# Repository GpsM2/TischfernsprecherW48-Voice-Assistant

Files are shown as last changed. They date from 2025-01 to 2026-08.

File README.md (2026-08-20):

# 📞 TischfernsprecherW48-Voice-Assistant 🗣️


Modification of a vintage "Tischfernsprecher W 48" telephone into a HomeAssistant-compatible voice assistant device

## 📝 Detailed Description
This project transforms the vintage "Tischfernsprecher W 48" telephone into a voice assistant. The device listens only when the handset is lifted, making it intuitive and eliminating the need for a wake word. Additionally, it combines the charm of a vintage telephone with modern functionality. ✨

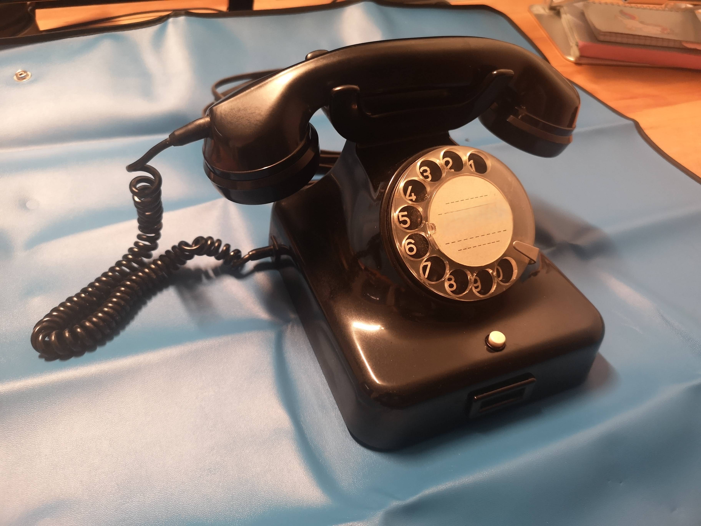
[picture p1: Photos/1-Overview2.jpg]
Phone


## 🛠️ Hardware Used
* [diymore ESP32 S3 DevKitC 1 N16R8 ESP32 S3 WROOM1 N16R8](https://www.amazon.de/gp/product/B0CLD4QKT1)
* [AZDelivery MAX98357A I2S 3W Mono Amplifier Class D](https://www.amazon.de/dp/B09PL7DSK5)
* [ARCELI 3PCS INMP441 Omnidirectional Microphone Module, I2S](https://www.amazon.de/dp/B0CH2TYXCZ)
* [Weewooday 6 Pieces 2W 8 Ohm Speaker](https://www.amazon.de/dp/B09MRK24PP)
* [chenyang RJ45 Stretch Spiral Cable Cat6 8P8C UTP](https://www.amazon.de/dp/B0CF2B2PCK) (at least 2 meters, 7 wires needed)

## 💻 Software Used
* [ESPHome](https://esphome.io/) **2026.4.0 or newer**, running as a Home Assistant add-on 🏠
* [YAML configuration file](tischfernsprecher-w48.yaml) 📄

### ⚙️ Setup
1. Copy [`secrets.yaml.example`](secrets.yaml.example) to `secrets.yaml` next to the configuration and fill in your Wi-Fi credentials and an API encryption key (generate one with `openssl rand -base64 32`). `secrets.yaml` is git-ignored and must stay out of the repository. If you are updating an existing device, reuse the key it already has — a new key means Home Assistant can no longer reach the device.
2. Adopt the configuration in the ESPHome dashboard and flash the device. It joins the configured network on its own; if that network is unreachable it opens its own access point and serves a captive portal, so it can be recovered without opening the housing.
3. In Home Assistant, assign an Assist pipeline to the device. Lifting the handset starts the pipeline — there is no wake word.

> **ESPHome version.** This configuration uses the current audio stack (`speaker` plus `media_player: speaker`). The older `media_player: i2s_audio` platform was **removed in ESPHome 2026.4.0**, so anything built from an earlier revision of this repository will no longer compile. The ESP-IDF framework is required and is already set in the configuration.

> **No PSRAM on this build.** The board is sold as an ESP32-S3 N16R8, which should mean 8 MB of octal PSRAM, but the one used here reports none: with `mode: octal` the second stage bootloader hangs before printing a single line, and with `mode: quad` the device boots and logs `PSRAM: Available: NO`. The configuration therefore ships without a `psram:` block, runs the whole audio chain at 16 kHz mono and keeps the media player buffer small enough for internal RAM. If your board does have working PSRAM, adding `psram:` back and raising `buffer_size` will give you better media playback.

### 🔄 Upgrading from an earlier revision

Anyone who built this device before the 2026 rewrite is on the old node name `esphome-web-c7b550`. The node is now called `w48-phone`, which means Home Assistant creates a fresh set of entity IDs (`binary_sensor.w48_phone_handset`, `media_player.w48_phone_speaker`, and so on) and leaves the old ones behind as unavailable.

After flashing, expect to:

1. Delete the orphaned entities of the old node in Home Assistant.
2. Re-point anything that referenced the old IDs — dashboards, automations, and the player entry in Music Assistant.
3. Re-assign the Assist pipeline and the area to the device.

If you would rather keep your existing entity IDs, set `substitutions: name:` back to your old node name before flashing. Everything else in this configuration works either way.

> **Optional: using the full 16 MB of flash.** `flash_size` is deliberately left at its default so that updates can be installed over the air. Setting `flash_size: 16MB` changes the partition table, and partition tables are not written during an OTA update — that change requires flashing over USB once.

## 🔧 Assembly Instructions
I removed the internal components of the telephone and replaced them with the new technology. Please refer to the uploaded images for detailed steps. 🔩

Feel free to use [my Fritzing file](Fritzing/Voice%20Assistant%20W48%20verkürzte%20Kabelwege.fzz).

<table>
  <tr>
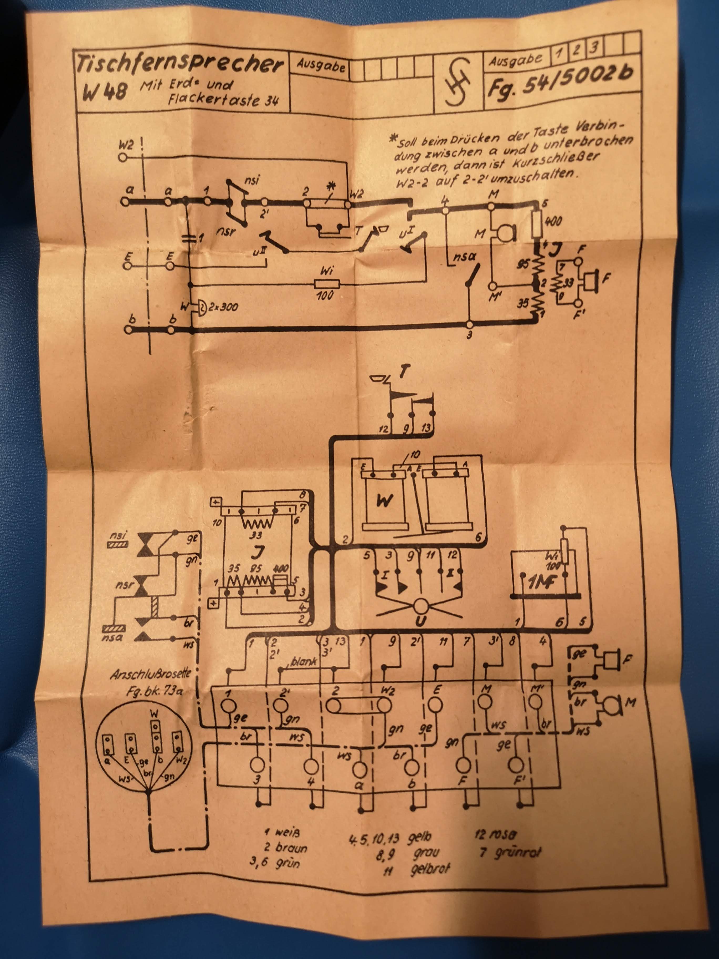
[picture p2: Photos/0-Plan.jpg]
Planungsübersicht
    <td align="center">Original plan<br/></td>
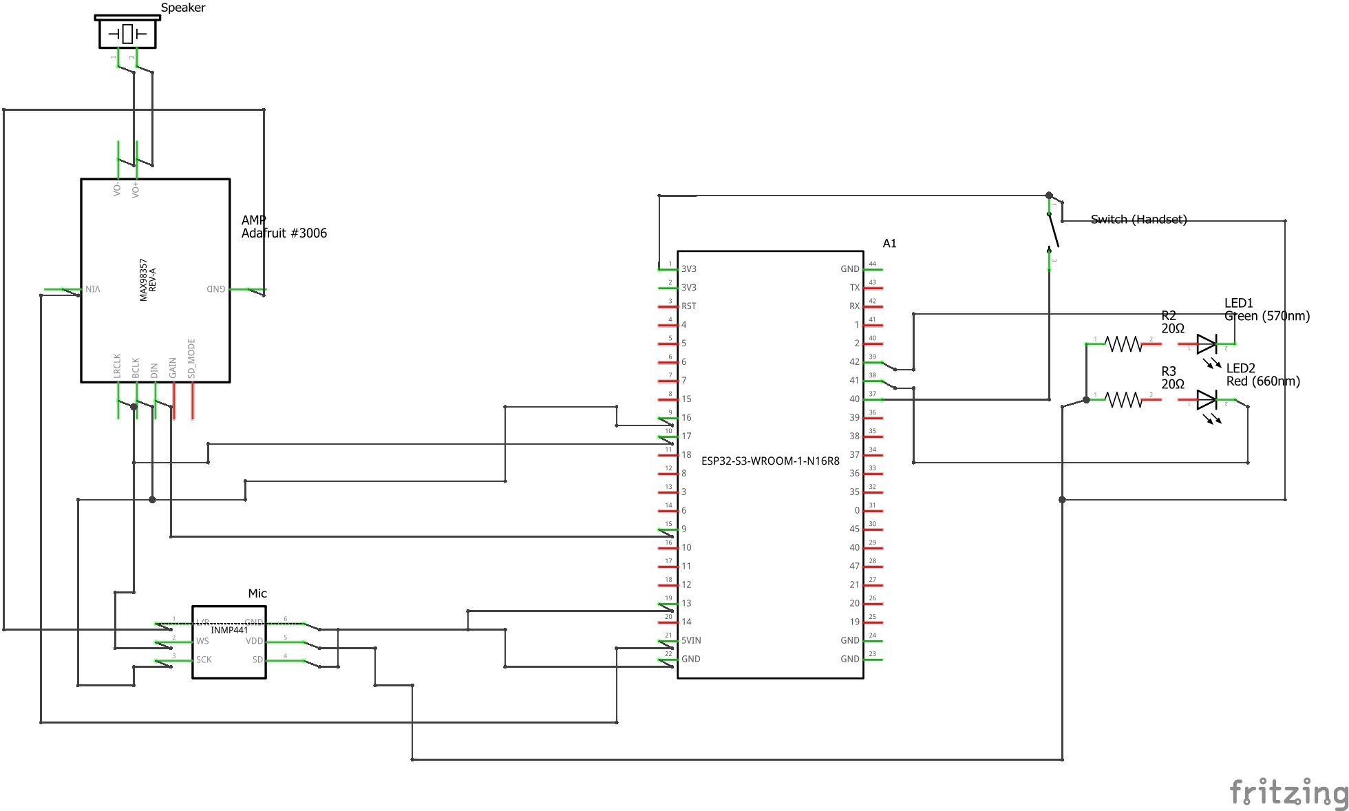
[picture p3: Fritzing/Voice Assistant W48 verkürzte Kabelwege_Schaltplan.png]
Fritzing Schaltplan
    <td align="center">Fritzing Schaltplan<br/></td>
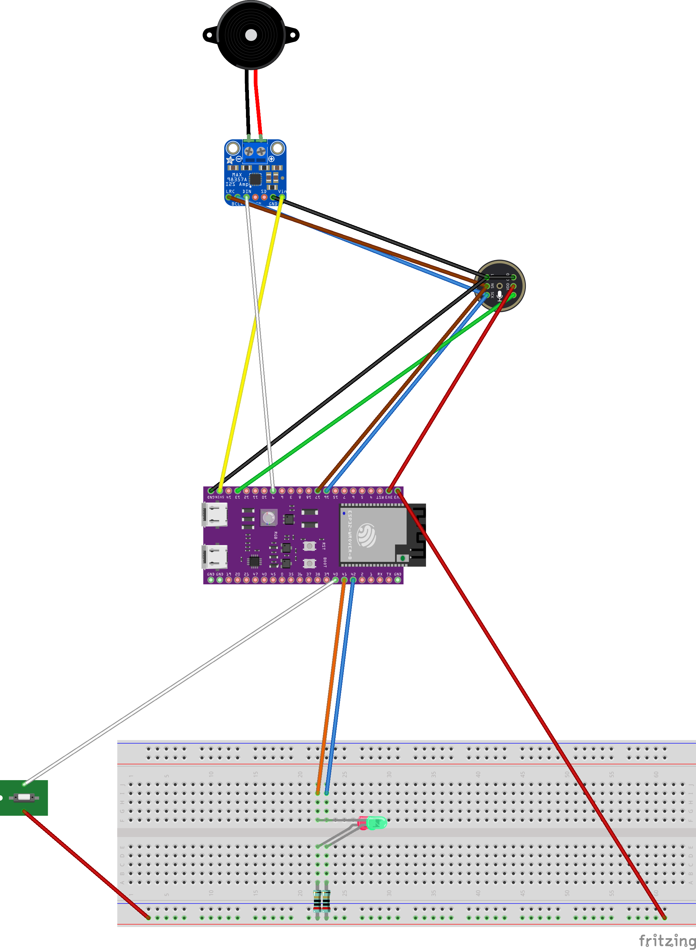
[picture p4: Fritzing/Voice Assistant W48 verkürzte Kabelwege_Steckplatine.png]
Fritzing Steckplatine
    <td align="center">Fritzing Steckplatine<br/></td>
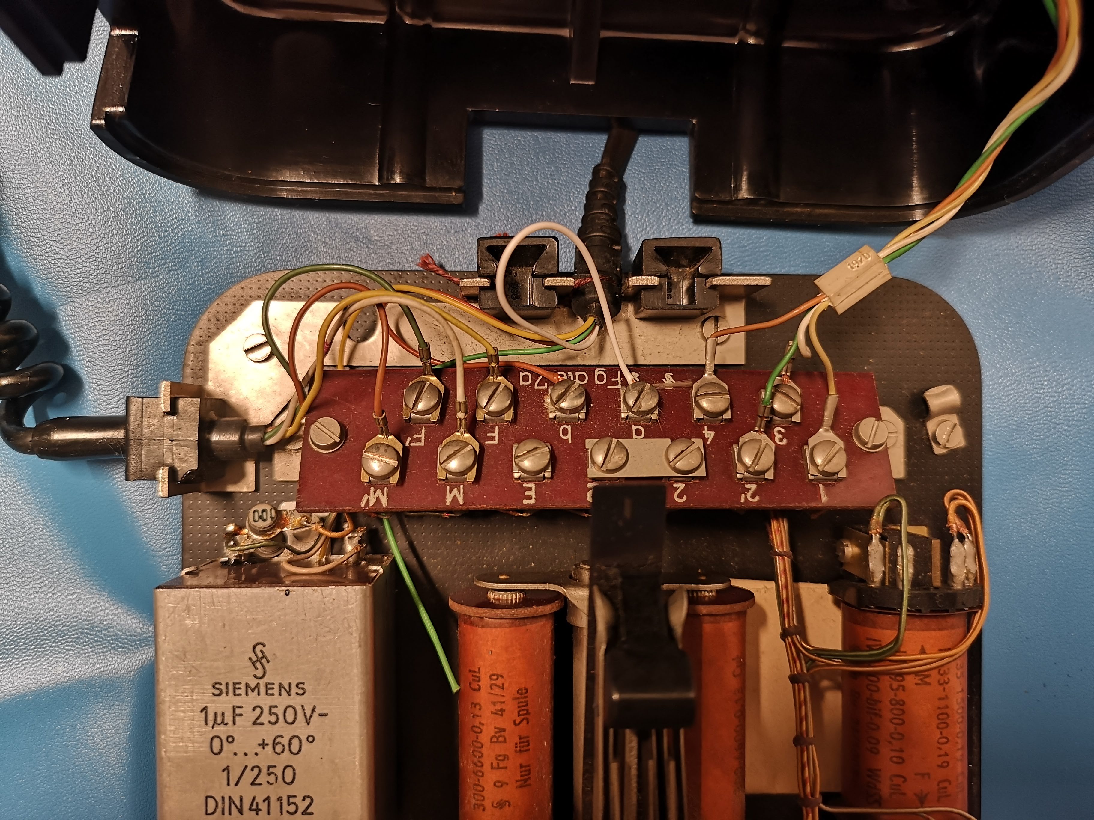
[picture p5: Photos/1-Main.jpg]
Hauptansicht Phase 1
    <td align="center">Before - Main<br/></td>
    <td align="center">Before - Overview<br/>Übersicht der Komponenten Phase 1</td>
  </tr>
  <tr>
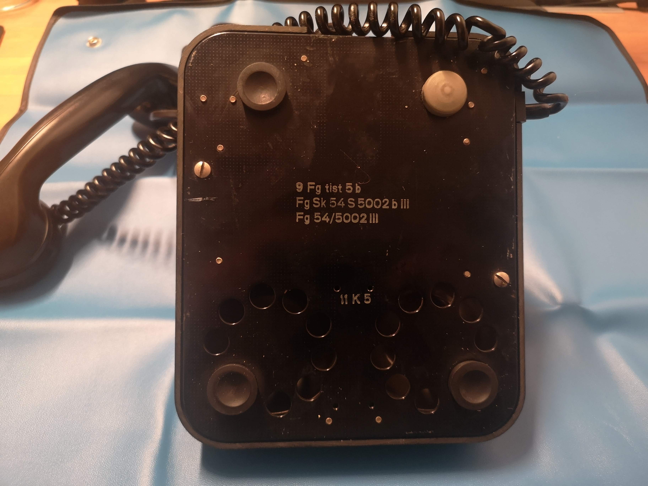
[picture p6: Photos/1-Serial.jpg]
Serielle Verbindung/Verkabelung
    <td align="center">Before - Serial<br/></td>
    <td align="center">After - Main<br/>Hauptansicht Phase 2</td>
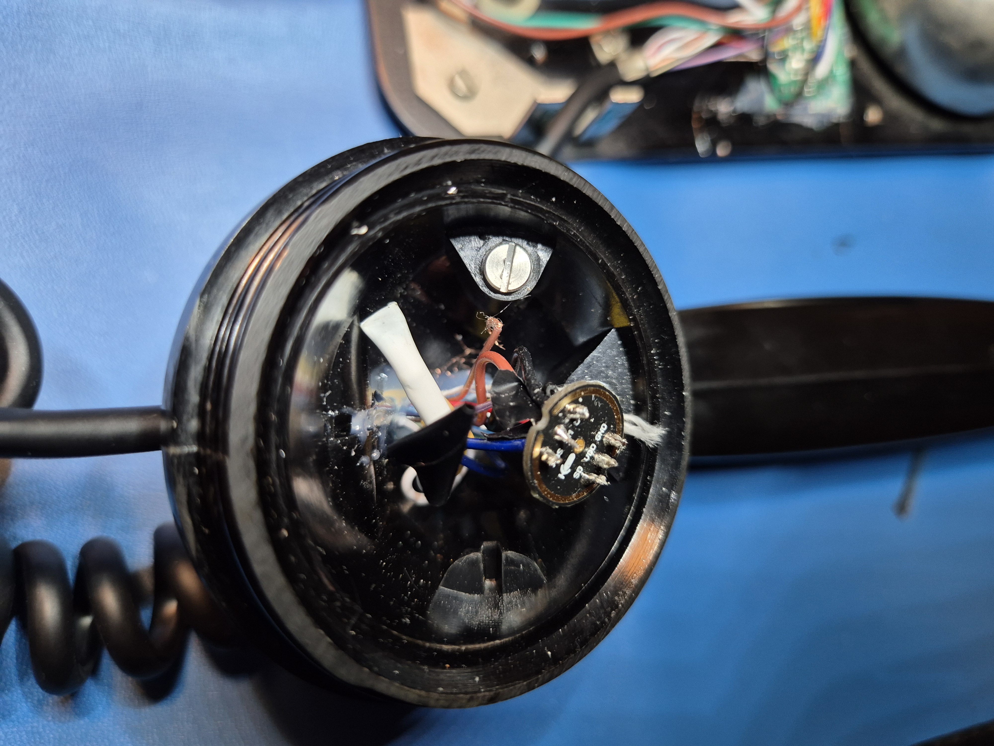
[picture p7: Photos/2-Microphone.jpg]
Mikrofonintegration
    <td align="center">After - Microphone<br/></td>
    <td align="center">After - Overview<br/>Übersicht Phase 2</td>
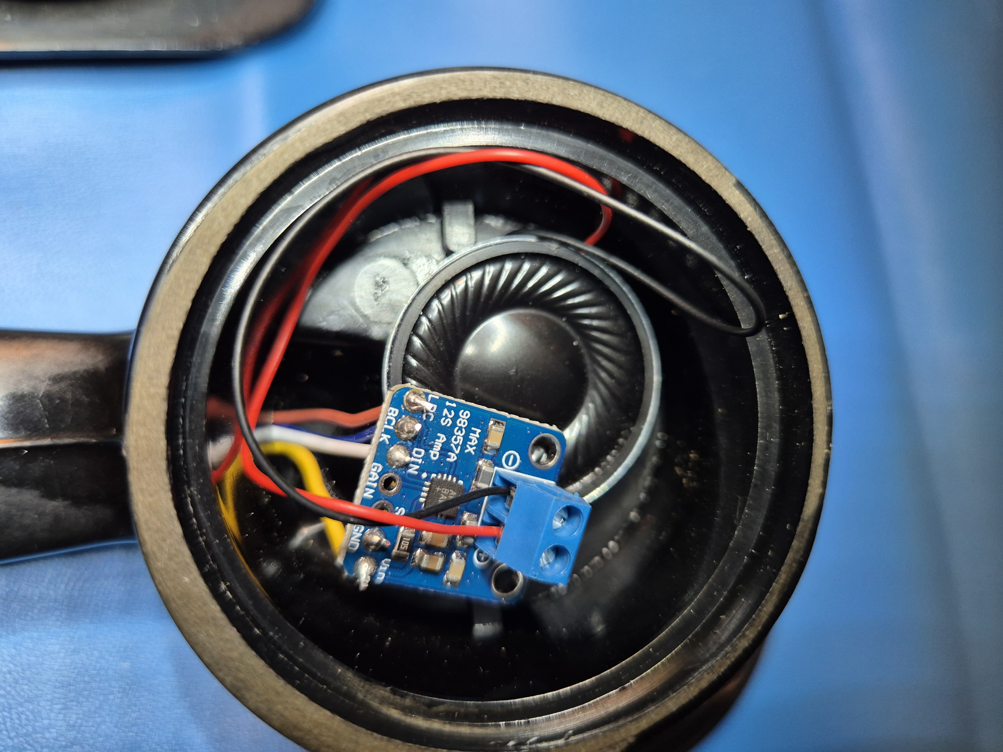
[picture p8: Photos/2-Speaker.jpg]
Lautsprecherintegration
    <td align="center">After - Speaker<br/></td>
  </tr>
</table>

## 💡 Usage Notes
Improvements are welcome! 🙌 The internal assembly could be more space-efficient, allowing the bell 🔔 to be operated with an electromagnet. A custom PCB design could also be beneficial. Ensure proper strain relief for the spiral cable. The cable I used conveniently included a rope, allowing strain relief in the handset with a screw and hot glue. 👍

## 📄 License

This project is licensed under the [Creative Commons Attribution-ShareAlike 4.0 International License](LICENSE) (CC BY-SA 4.0) — the ESPHome configuration, the documentation, the photos and the Fritzing file alike.

You are free to share and adapt the material, including commercially, as long as you give appropriate credit and distribute your contributions under the same license.

Attribution: *TischfernsprecherW48-Voice-Assistant* by [GpsM2](https://github.com/GpsM2), licensed under CC BY-SA 4.0.

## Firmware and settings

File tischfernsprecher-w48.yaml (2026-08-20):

substitutions:
  # Changing the node name renames every entity ID in Home Assistant.
  # Check what points at the old IDs before touching this.
  name: w48-phone
  friendly_name: W48 Phone

esphome:
  name: ${name}
  friendly_name: ${friendly_name}
  name_add_mac_suffix: false
  # The speaker media player used below requires 2026.4.0 or newer.
  min_version: 2026.4.0
  platformio_options:
    board_build.flash_mode: dio
  project:
    name: gpsm2.tischfernsprecher-w48
    version: '1.1.6'

esp32:
  board: esp32-s3-devkitc-1
  framework:
    # ESP-IDF is the default since ESPHome 2026.1.0 and is what the speaker
    # media player expects. Do not switch back to arduino.
    type: esp-idf

# No psram: block on purpose. The board is sold as an N16R8, which would mean
# 8 MB of octal PSRAM, but this one reports none: with mode octal the second
# stage bootloader hangs before it prints anything, and with mode quad the
# device boots and logs "PSRAM: Available: NO". Everything below is therefore
# sized for internal RAM only.

logger:

# Enable Home Assistant API
api:
  encryption:
    key: !secret api_encryption_key

# Allow Over-The-Air updates
ota:
  - platform: esphome
    # The running firmware is what checks this password, not the one being
    # uploaded. Changing the value means the next OTA is rejected and the
    # device has to be flashed over USB once.
    password: !secret ota_esphome_key

wifi:
  ssid: !secret wifi_ssid
  password: !secret wifi_password
  # Fallback access point. If the configured network is unreachable, the device
  # opens its own and serves the captive portal below, so it can be recovered
  # without opening the housing.
  ap:

captive_portal:

# Microphone and amplifier share one I2S bus, because they share the BCLK and
# LRCLK wires in the hardware. ESPHome serialises access with a mutex, so only
# one of them can hold the bus at a time - recording and playback alternate.
# That is why the voice assistant must not be left running while the handset is
# down: a microphone that never lets go means the speaker never gets the bus.
i2s_audio:
  - id: i2s_in
    i2s_lrclk_pin: GPIO17 #WS Pin from the INMP441 Microphone
    i2s_bclk_pin: GPIO16 #SCK Pin from the INMP441 Microphone

microphone:
  - platform: i2s_audio
    adc_type: external
    pdm: false
    id: mic_i2s
    channel: left
    bits_per_sample: 32bit
    i2s_audio_id: i2s_in
    i2s_din_pin: GPIO13  #SD Pin from the INMP441 Microphone

speaker:
  - platform: i2s_audio
    id: i2s_speaker_out
    i2s_audio_id: i2s_in
    dac_type: external
    i2s_dout_pin: GPIO09   #  DIN Pin of the MAX98357A Audio Amplifier
    channel: mono
    # 16 kHz is what Home Assistant's text to speech delivers, and a W48
    # handset earpiece is bandwidth limited far below that anyway. Running the
    # whole chain at 16 kHz mono keeps the buffers small, which matters because
    # there is no PSRAM.
    sample_rate: 16000
    bits_per_sample: 16bit
  # The announcement and media pipelines are not allowed to share one speaker,
  # so the mixer splits the single physical amplifier into two virtual ones.
  - platform: mixer
    id: speaker_mixer
    output_speaker: i2s_speaker_out
    source_speakers:
      - id: announcement_speaker
      - id: media_speaker

media_player:
  - platform: speaker
    name: "Speaker"
    id: media_player_speaker
    # Default is 1 MB, which lives in PSRAM on boards that have it. This one
    # does not, so the allocation has to fit in internal RAM.
    buffer_size: 64000
    announcement_pipeline:
      speaker: announcement_speaker
      format: FLAC
      sample_rate: 16000
      num_channels: 1
    media_pipeline:
      speaker: media_speaker
      format: FLAC
      sample_rate: 16000
      num_channels: 1

voice_assistant:
  microphone: mic_i2s
  id: va
  noise_suppression_level: 2
  auto_gain: 31dBFS
  volume_multiplier: 10.0
  use_wake_word: false
  media_player: media_player_speaker
  on_listening: #Switches the green LED on and red off when listening
    - switch.turn_on:
        id: status_led_green
    - switch.turn_off:
        id: status_led_red
  on_end:
    - switch.turn_off:
        id: status_led_green
    - switch.turn_on:
        id: status_led_red
    # Only keep listening while the handset is actually off the cradle.
    # handset is ON when lifted, so this must be is_on - with the inverted pin
    # logic this repository used before, the same condition was true while the
    # handset was resting and restarted the assistant in an endless loop.
    - if:
        condition:
          binary_sensor.is_on: handset
        then:
          - voice_assistant.start_continuous
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

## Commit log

2025-01-06 Initial commit with circuit diagram and images
2026-08-20 Add CLAUDE.md with binding development rules
    Damit Workflow, Umgang mit externen Pull Requests und das Release-Verfahren
    nicht bei jeder Session neu ausgehandelt werden muessen, sind die Regeln
    jetzt im Repo festgeschrieben statt nur im Kopf des Maintainers.
    Die Versionierungsregel wurde von manifest.json auf esphome.project.version
    uebertragen: manifest.json gehoert zu HACS-Integrationen, dieses Repo ist
    eine ESPHome-Konfiguration. project.version ist hier die einzige nach
    aussen sichtbare Version, sie erscheint in Home Assistant als sw_version.
2026-08-20 Migrate to the current ESPHome audio stack
    The configuration in this repository could no longer be built. ESPHome
    removed the i2s_audio media player in 2026.4.0, together with the legacy
    I2S driver it was based on; upstream the component is now a stub that
    rejects every configuration. Anyone cloning this repository ran into a
    hard config error, and existing devices could not be rebuilt or updated
    over the air.
    Verified against a local ESPHome 2026.8.0 installation: the previous file
    fails with "The I2S audio media player has been removed", the new one
    passes "esphome config".
    Audio output is rebuilt on speaker + media_player: speaker. The route via
    media_player was chosen over the leaner v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
    [tischfernsprecher-w48.yaml]
2026-08-20 Version the migration as 1.1.0 instead of 2.0.0
    Maintainer decision. The framework switch and the rebuilt audio stack do
    not change what the device does or how it is operated, so a minor bump
    communicates the change more honestly than a major one.
2026-08-20 Add CC BY-SA 4.0 license
    The README invites people to rebuild the device and improve on it, and the
    repository hands out the pieces to do so - configuration, Fritzing drawing,
    photos. Without a license none of that may legally be reused, which
    contradicts what the project is obviously for.
    CC BY-SA 4.0 chosen by the maintainer. It fits a repository whose weight
    sits in documentation, drawings and photographs rather than in code, and
    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
2026-08-20 Fix build: rename mixer ID away from the component namespace
    main does not compile. The mixer introduced in #1 was given the ID
    mixer_speaker, and ESPHome turns an ID into a global variable of that
    name - but the component's namespace is called mixer_speaker as well.
    Every use in the generated main.cpp is therefore ambiguous:
    error: reference to 'mixer_speaker' is ambiguous
    candidates are: 'namespace esphome::mixer_speaker { }'
    'esphome::mixer_speaker::MixerSpeaker* const mixer_speaker'
    esphome config never sees this. It validates the YAML and generates no
    C++ at all, so a name collision in the generated source is outside what
    it can detect - the configuration is vali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
    [tischfernsprecher-w48.yaml]
2026-08-20 Rename node and entities to readable English names
    The node was still called esphome-web-c7b550, the generated name from the
    ESPHome Web adoption flow, and friendly_name described the chip rather
    than the device. Neither told anyone what this thing is. Entity names were
    a German/English mix, and "Schalter Hoerer" produced the entity ID
    schalter_h_rer because the umlaut is dropped during sanitising.
    Node is now w48-phone / "W48 Phone", entities are Handset, Speaker,
    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
2026-08-20 Take Wi-Fi credentials from secrets instead of Improv provisioning
    Anyone using this configuration has to create a secrets.yaml anyway, for
    the API encryption key. Improv only helps someone who never opens the
    configuration, and that person does not exist here - so two more lines in
    a file that is being edited regardless beat a Bluetooth provisioning
    round at a device that sits inside a screwed-shut wooden housing.
    Improv and the BLE automations go with it, because both cannot coexist:
    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
2026-08-20 Adapt the configuration to the hardware that is actually there
    First flash on real hardware. Four things were wrong, three of them
    assumptions I had made from the board label and the schematic rather than
    from evidence.
    The board reports no PSRAM. It is sold as an N16R8, which should mean 8 MB
    of octal PSRAM, but with mode octal the second stage bootloader hangs right
    after "entry 0x403c891c" without printing a single line, and with mode quad
    the device boots and logs "PSRAM: Available: NO". The psram block is gone,
    the whole audio chain now runs at 16 kHz mono, and the media player buffer
    drops from the 1 MB default - which lives in PSRAM on boards that have it -
    to 64000 bytes so it fits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
    [tischfernsprecher-w48.yaml]
